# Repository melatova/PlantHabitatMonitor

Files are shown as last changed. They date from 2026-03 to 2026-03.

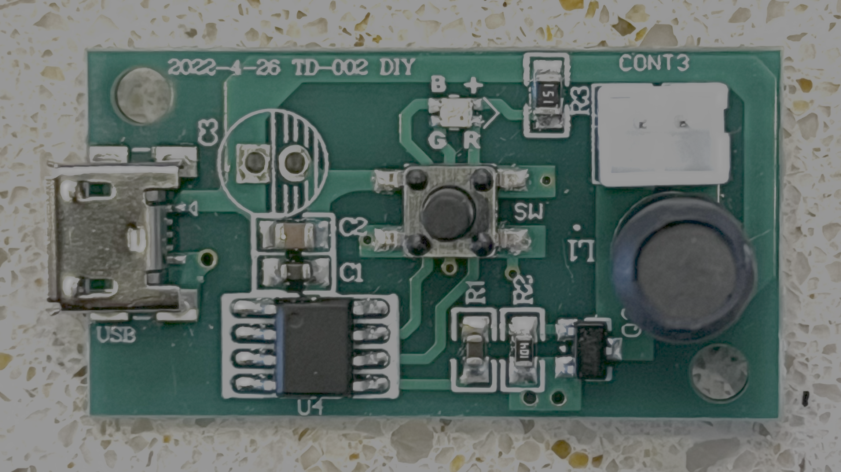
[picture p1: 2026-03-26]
images/Piezo_atomizer_board_TD-002-DIY-front.png

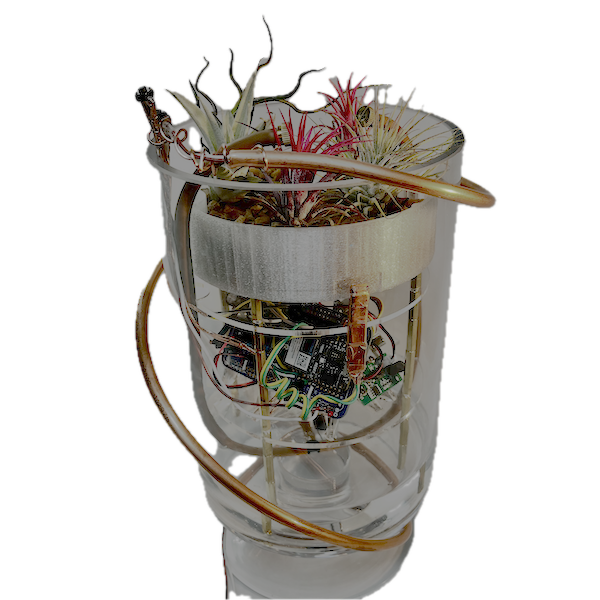
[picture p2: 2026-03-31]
images/Air_plant_sanctuary_2.png

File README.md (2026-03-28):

# 🌿 PlantHabitatMonitor
> **The Electro-Natural Plant Tech Sensor Menagerie**



[]()


---

### 🍃 Smart Tillandsia Care 
**A Multi‑Tiered IoT Air Plant Habitat**

```text
       [  plant  ]
            │
            │
    [sensors + display]
            │
            │
    [ water reservoir ]
    └─────────────────┘

A compact, slightly over‑engineered IoT habitat designed top  
Tillandsia (air plants) alive — despite my historically poor track record.

Built in five and a half days as part of a CNM IoT assignment,  
this project combines environmental sensing, automatic misting,  
and cloud monitoring in a sculptural glass enclosure.

* * * * * * * * * * * * * * * *

Features

  * Environmental monitoring**
    * Temperature & humidity (BME280)
    * Air quality sensing (analog gas sensor)
    * Capacitive moisture detection
    * Water reservoir level sensing

  * Automated plant care**
    * Piezo atomizing mist system
    * Water pump with automatic and manual control

  * Visual feedback**
    * NeoPixel status lighting
    * OLED system display with multiple pages

  * Cloud integration**
    * Live data publishing
    * Remote manual control via Adafruit IO dashboard

  * Modular physical design**
    * Multi‑tier vertical architecture
    * Custom laser‑cut and 3D‑printed structural components
    * Designed to live inside a glass hurricane vase

······························

System Architecture

Main loop structure:

loop()
├── readSensors()
├── updateButtons()
├── evaluateTriggers()
├── controlPumpAndMister()
├── updateNeoPixels()
├── updateOLED()
└── publishCloudData()

The system supports both automatic and manual operation modes,  
with local controls mirrored in the cloud dashboard.

······························

Hardware

  * Particle Photon 2**
  * BME280 temperature / humidity sensor**
  * Analog air quality sensor**
  * Capacitive moisture sensor**
  * DIY silver‑wire water level probes**
  * Piezo atomizer (TD‑002) + disc**
  * Water pump**
  * NeoPixel LED rings**
  * SSD1306 OLED display (I²C)**
  * MOSFET‑based power switching (post‑redesign)**

······························

Pinout (Core Signals)

| Component                | Pin |
|--------------------------|-----|
| OLED SDA / I²C           | D0  |
| OLED SCL / I²C           | D1  |
| NeoPixel Data            | D2  |
| Pump MOSFET Gate         | D4  |
| Mist MOSFET Gate         | D5  |
| Mist Button              | D7  |
| Mode Button              | D9  |
| Soil / Moisture Sensor   | A0  |
| Air Quality Sensor       | A1  |
| Reservoir Probe (ADC)    | A2  |

······························

Design Challenges & Lessons

  * Hardware that works on a home desk doesn’t always work at your away desk
  * Current draw issues revealed limitations of relay‑based switching
  * Redesigning the power stage with MOSFETs improved reliability
  * Wire routing and noise isolation matter in mixed‑signal systems
  * Iteration is unavoidable — and educational

······························

Piezo Atomizer Notes

The misting system uses a TD‑002 piezo atomizer module  
driven via a MOSFET rather than a relay due to current draw spikes.

Key considerations:
  * High‑frequency operation (~110 kHz)
  * 5V supply with adequate current headroom
  * Physical isolation from I²C wiring to reduce interference

Close‑up imagery and test videos are included in the project gallery.

······························

Gallery

https://youtu.be/lMnhnqs0L-Q

System Planning  
(images/planning_circuit_layer_arrangment.png)

Breadboard Prototyping  
(images/breadboard_testing.png)

MOSFET Redesign  
(images/changing_from_relays_to_MOSFETS.png)

Piezo Atomizer Detail  
(images/piezo_atomizer_plate.png)

Cloud Dashboard  
(images/adafruit_Dashboard.png)

Final Habitat  (updated as project progresses)
(images/PlantHabitatMonitor03.png)

······························

Files

/src        — firmware  
/images     — photos + macros  
/docs       — diagrams + notes  
/mechanical — laser‑cut + printed parts  

······························

Why This Exists

This project exists because air plants are beautiful, fragile,  
and completely unwilling to tolerate guesswork.

Rather than give up, I decided to give them sensors, firmware,  
and a cloud dashboard — and see what happened.

So far: the plants are alive.

······························

License

MIT License — enjoy, remix, and keep plants alive thoughtfully 🌿

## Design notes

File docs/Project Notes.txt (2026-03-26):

Plant Habitat Monitor Project 

---------------------------------------------------------

Take care of a plant and see how it's doing!

 ─────────────────────────────────────────────
   Hardware:
 ─────────────────────────────────────────────

     Device OS  : 5.8.0  (best for NeoPixels on Photon 2)
     NeoPixel   : D2, WS2812B, 24 LEDs (2x12 rings)
     BME280     : I2C 0x76
     OLED       : SSD1306 128x64, I2C 0x3C
     Soil sensor: A0 (capacitive)
     Air quality: A1 (Grove MP-503)
     Pump relay : D4
     Mist relay : D5
     Mode button: D9  (long=AUTO/MANUAL, short=advance OLED page)
     Mist button: D7  (dedicated tap for manual mist burst)
 ─────────────────────────────────────────────
   See plant data and control mister and pump

	Adafruit Dashboard Feeds
 ─────────────────────────────────────────────

     PUBLISH  -> temperature, humidity, plant-status,
                airreading, mode
     SUBSCRIBE<- pumponoff, misteronoff, pumpslider,
                modetoggle

 ─────────────────────────────────────────────
   Determine when habitat needs water

		THRESHOLDS
 ─────────────────────────────────────────────

  Calibration notes: air=3392, wet soil=3335, dry soil=3360, water=1460
  Air plants in gravel will sit closer to the dry end

SOIL_DRY_VALUE    = 3200;
SOIL_WET_VALUE    = 1500;
SOIL_WATER_THRESH = 30% below -> auto-water

MIST_TEMP_THRESH  = 30.0;    deg C above -> consider misting
MIST_HUM_THRESH   = 25.0;    %RH below  -> auto-mist fires

─────────────────────────────────────────────
   Display with environmental information

		OLED PAGES
─────────────────────────────────────────────
	
	PAGE_PLANT
	PAGE_CLIMATE
	PAGE_DEVICES
	PAGE_MODE
	"WATERING!" screen if pump is running
	"MISTING!"  screen while misting

starts with PAGE_PLANT

 ─────────────────────────────────────────────
   Continuously check plant environment

		LOOP
 ─────────────────────────────────────────────

	Sensor read every 10 s

	If in Auto Mode, waters plant if dry

	Keeps MQTT connection alive
   
	Publishes every 30 min

	Scrolls through OLED pages via 

	Shows Watering and Misting pages when activated
 
	Lights up neoPixels

  ─────────────────────────────────────────────
   Get readings from various sensors

		SENSOR READS
  ─────────────────────────────────────────────
	Converts soil moisture to percent
	Converts temperature to Farenheit
	Determines air quality from the readings

    tempC     = bme.readTemperature();
    humidRH   = bme.readHumidity();
    tempF     = tempC * 1.8 + 32;
    pressPA   = bme.readPressure();
    pressInHg = 0.0002953 * pressPA;
    soilRaw   = analogRead(SOIL_MOISTURE_PIN);
    soilPct   = mapSoilToPercent(soilRaw);
    airReading = airSensor.getValue();
    airQuality = airSensor.slope();

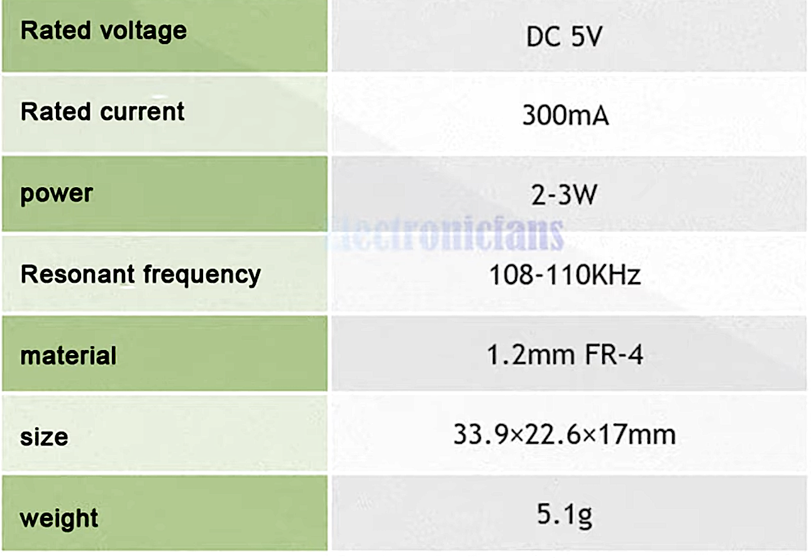
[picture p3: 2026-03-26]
docs/TD-002_specs.png

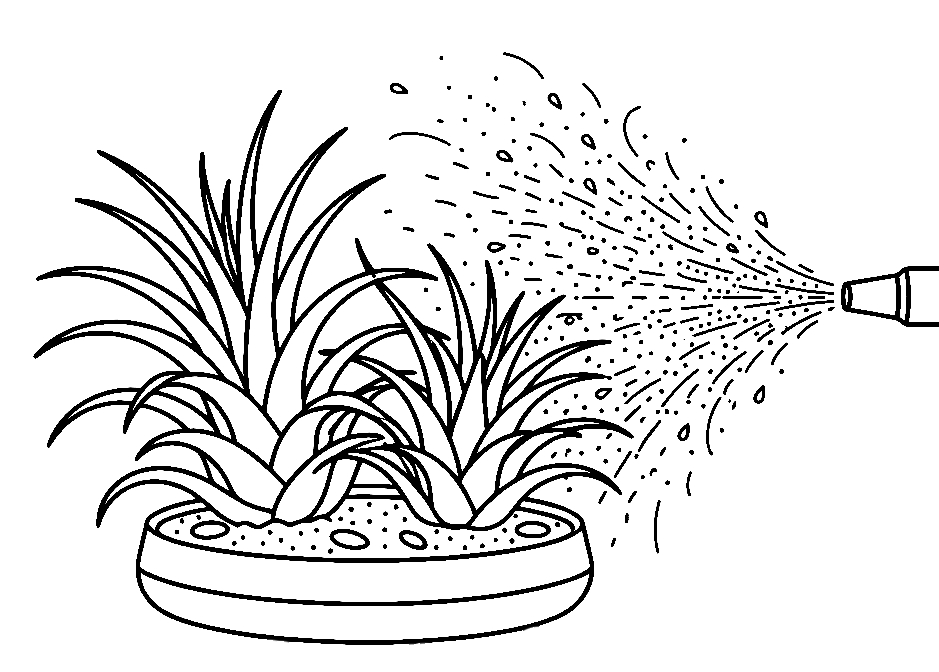
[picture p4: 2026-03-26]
images/Concept_Airplants_in_Gravel_auto_watering.png

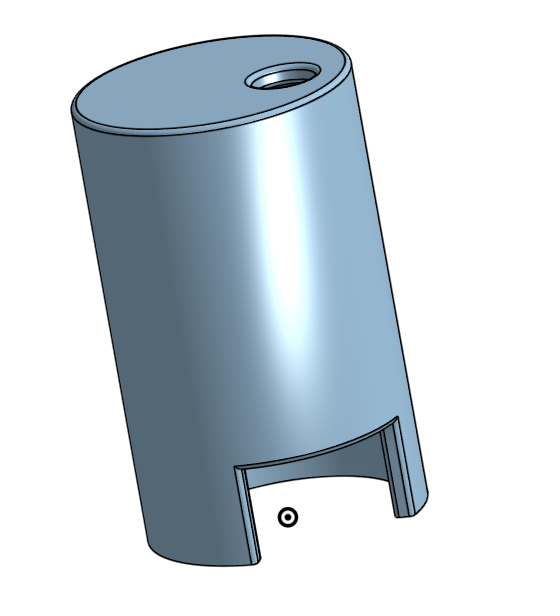
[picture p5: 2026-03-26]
mechanical/pump_cover.png

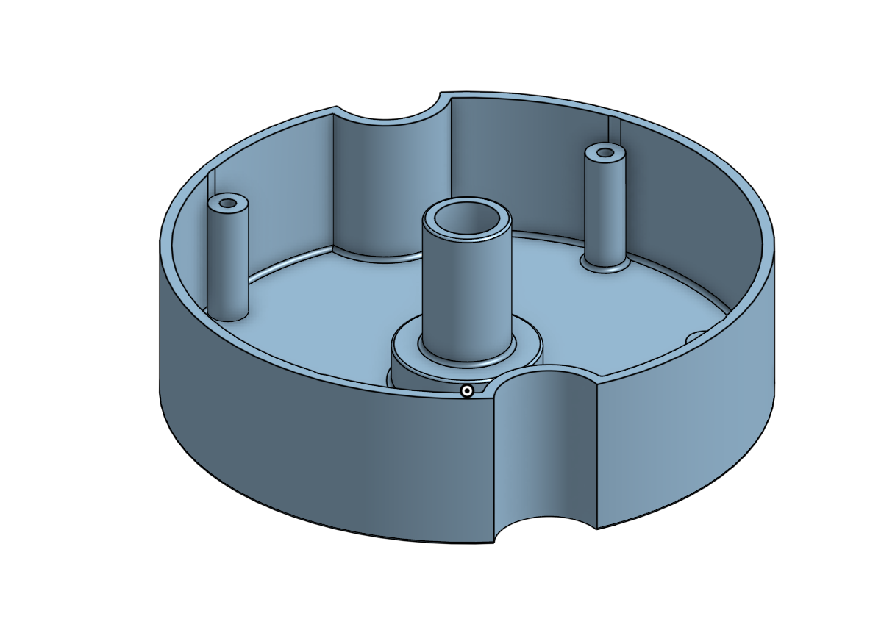
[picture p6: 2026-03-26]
mechanical/Gravel_dish_for_air_plants.png

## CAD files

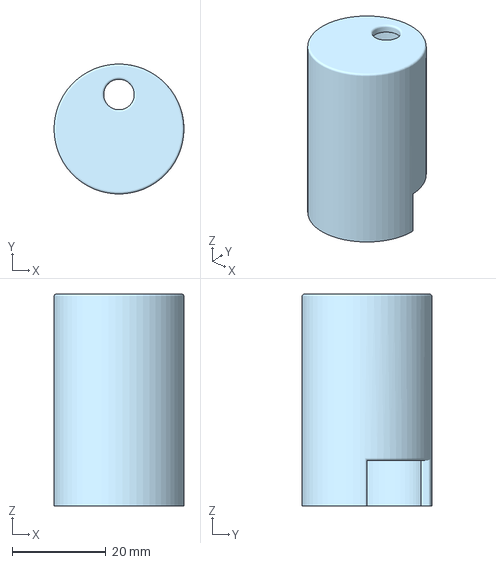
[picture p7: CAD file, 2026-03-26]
mechanical/5V_motorCover_sanderLegsFirst_printSmallHoleDown.3mf
27.7 x 27.7 x 45.2 mm

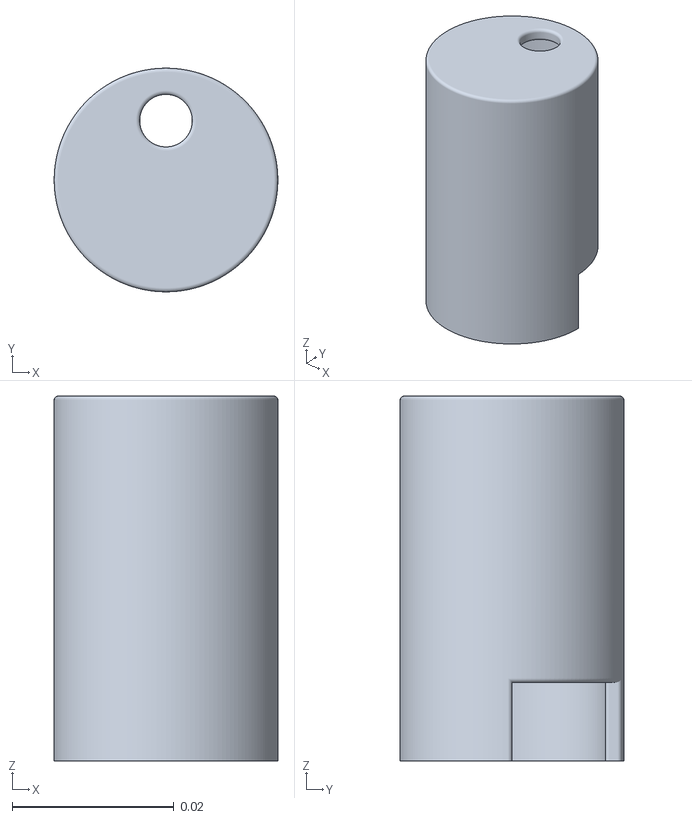
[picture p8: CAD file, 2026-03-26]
mechanical/5VMotorCover.stl
0.0277 x 0.0277 x 0.0452

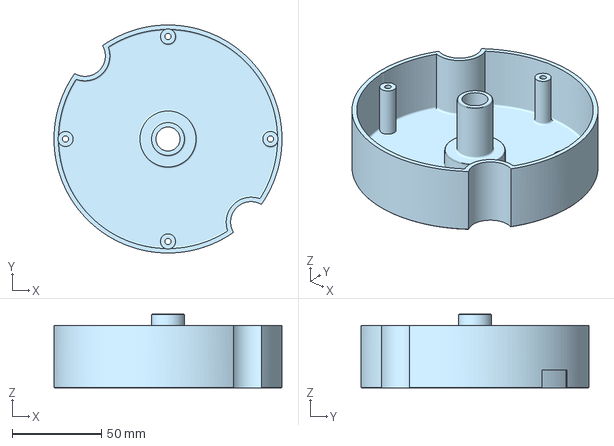
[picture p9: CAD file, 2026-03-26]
mechanical/Plant_habitat_gravel_dish.3mf
128.0 x 128.0 x 41.5 mm

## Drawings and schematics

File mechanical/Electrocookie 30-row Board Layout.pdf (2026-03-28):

# Electrocookie 30-row Board Layout — Plant Habitat Monitor

Photon 2 | 5V power rail | GND rail (16AWG copper loop) | MOSFET circuit | Sensors

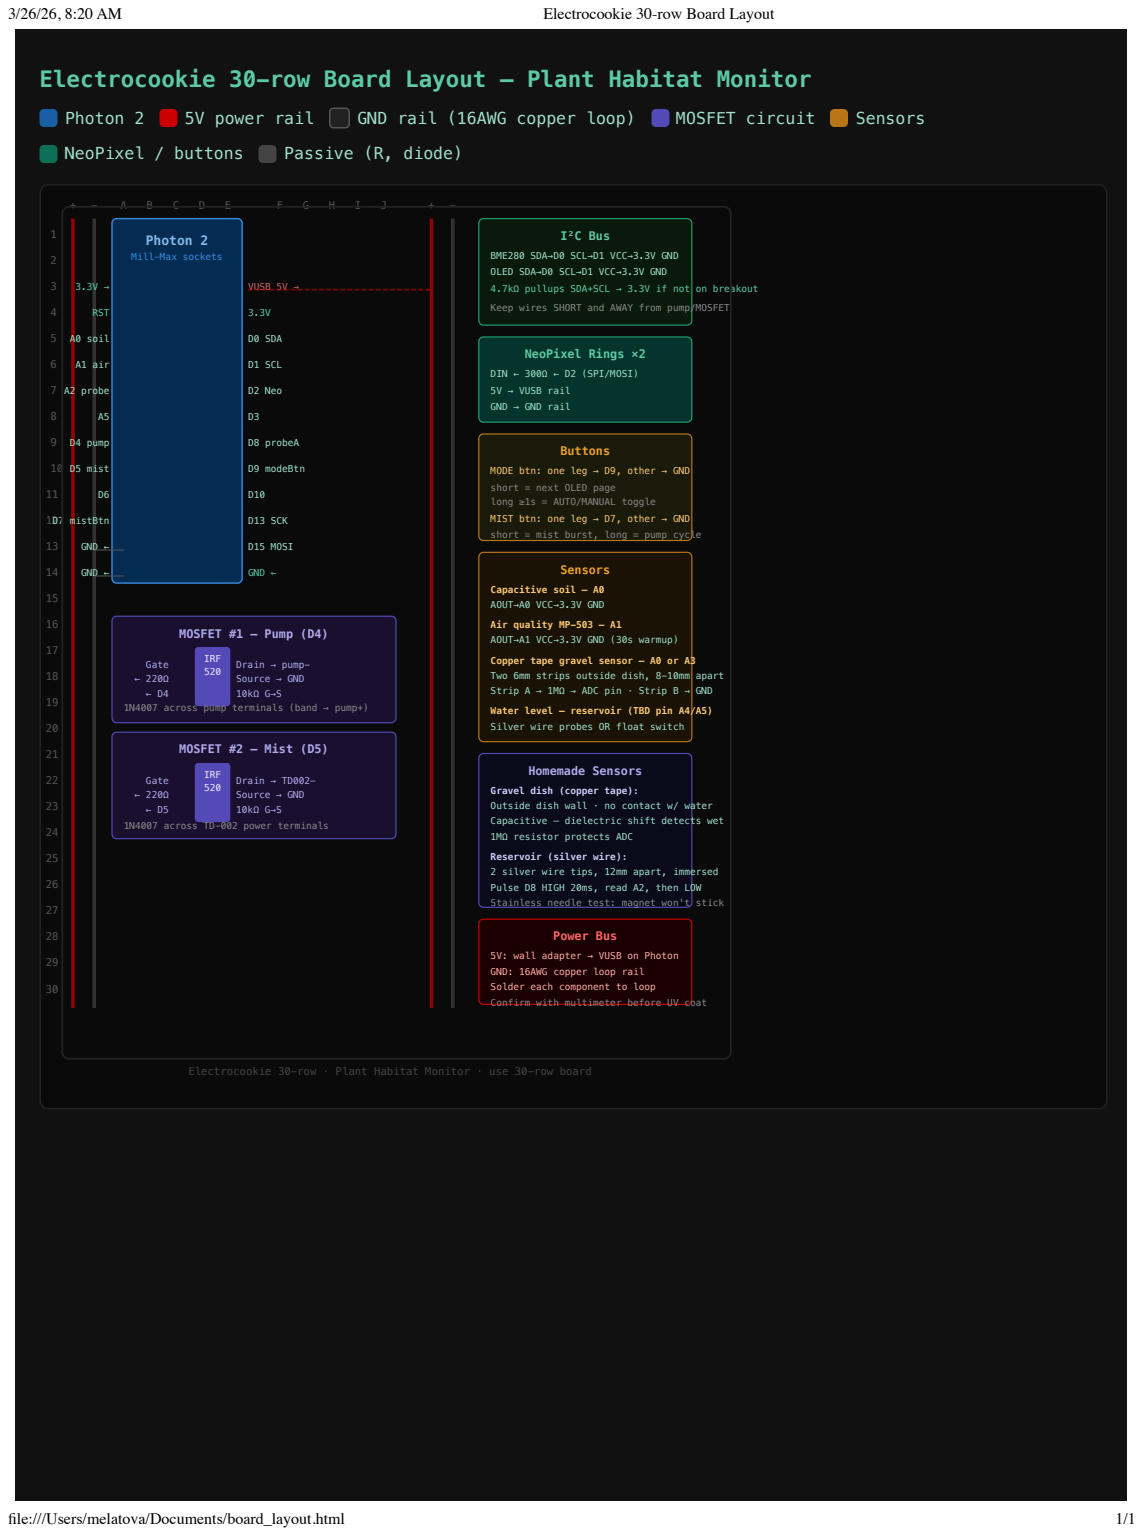
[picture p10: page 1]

BME280 SDA→D0 SCL→D1 VCC→3.3V GND
OLED SDA→D0 SCL→D1 VCC→3.3V GND
4.7kΩ pullups SDA+SCL → 3.3V if not on breakout
Keep wires SHORT and AWAY from pump/MOSFET

MODE btn: one leg → D9, other → GND
short = next OLED page
long ≥1s = AUTO/MANUAL toggle
MIST btn: one leg → D7, other → GND
short = mist burst, long = pump cycle

Capacitive soil — A0
AOUT→A0 VCC→3.3V GND
Air quality MP-503 — A1
AOUT→A1 VCC→3.3V GND (30s warmup)
Copper tape gravel sensor — A0 or A3
Two 6mm strips outside dish, 8-10mm apart
Strip A → 1MΩ → ADC pin · Strip B → GND
Water level — reservoir (TBD pin A4/A5)
Silver wire probes OR float switch

Gravel dish (copper tape):
Outside dish wall · no contact w/ water
Capacitive — dielectric shift detects wet
1MΩ resistor protects ADC
Reservoir (silver wire):
2 silver wire tips, 12mm apart, immersed
Pulse D8 HIGH 20ms, read A2, then LOW
Stainless needle test: magnet won't stick

5V: wall adapter → VUSB on Photon
GND: 16AWG copper loop rail
Solder each component to loop
Confirm with multimeter before UV coat

Electrocookie 30-row · Plant Habitat Monitor · use 30-row board

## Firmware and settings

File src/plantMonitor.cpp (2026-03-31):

// ============================================================
//  Project     :  Plant Habitat Monitor
//  Author      :  Nicole
//  Date        :  2/20/26  (updated 3/30)
//  Description :  Smart plant monitor — auto watering + misting,
//                 two DIY resistive moisture sensors, manual buttons,
//                 Adafruit IO dashboard, OLED display, NeoPixel ring.
//
//  Hardware confirmed working:
//    Device OS  : 5.8.0  (best for NeoPixels on Photon 2)
//    NeoPixel   : SPI1,  WS2812B, 12 LEDs (1 × 12-LED ring)
//    BME280     : I2C 0x76
//    OLED       : SSD1306 128×64, I2C 0x3C
//    Gravel sensor  : A5 (power pulse), A0 (analog read)  threshold 500–1500
//    Reservoir sensor: D8 (power pulse), A2 (analog read)  threshold 500
//    Air quality: A1 (Grove MP-503)
//    Pump MOSFET: D4
//    Mist MOSFET: D5
//    Mode button: D9  (short = next OLED page, long = AUTO/MANUAL toggle)
//    Mist button: D7  (short = mist burst,     long = pump cycle)
//
//  Adafruit IO feeds:
//    PUBLISH  -> temperature, humidity, plant-status, airreading, mode
//    SUBSCRIBE<- pumponoff, misteronoff, modetoggle

//   Zapier       (email/SMS webhooks via Particle.publish)
//
//  Future: reservoir level feed, SMS alert, OLED bitmap graphics
// ============================================================

#include "Particle.h"
#include "credentials.h"
#include "IoTClassroom_CNM.h"
#include "Adafruit_GFX.h"
#include "Adafruit_SSD1306.h"
#include "gfxDisplay.h"
#include "Adafruit_BME280.h"
#include "Adafruit_MQTT/Adafruit_MQTT_SPARK.h"
#include "Adafruit_MQTT/Adafruit_MQTT.h"
#include "neopixel.h"
#include "Colors.h"
#include "Air_Quality_Sensor.h"

// SYSTEM_THREAD(ENABLED) moves WiFi/cloud to a background thread
// so loop() never freezes waiting for network events.
SYSTEM_MODE(SEMI_AUTOMATIC);
SYSTEM_THREAD(ENABLED);

// ─────────────────────────────────────────────
//  PIN ASSIGNMENTS
// ─────────────────────────────────────────────
// Gravel dish sensor (air plants) — resistive, pulsed to prevent electrolysis
const int GRAVEL_POWER_PIN    = A5;  // OUTPUT — pulse HIGH to read
const int GRAVEL_ANALOG_PIN   = A0;  // INPUT  — analog read

// Water reservoir sensor — same resistive pulsed technique
const int RESERVOIR_POWER_PIN = D8;  // OUTPUT — pulse HIGH to read
const int RESERVOIR_ANALOG_PIN = A2; // INPUT  — analog read

const int AIR_QUALITY_PIN     = A1;  // Grove MP-503 analog out
const int PUMP_PIN            = D4;  // MOSFET gate — pump
const int MIST_PIN            = D5;  // MOSFET gate — TD-002 mister
const int MODE_BUTTON_PIN     = D9;  // INPUT_PULLUP — short/long press
const int MIST_BUTTON_PIN     = D7;  // INPUT_PULLUP — short/long press
// NeoPixel data -> SPI1 (confirmed working, Device OS 5.8.0)

// ─────────────────────────────────────────────
//  THRESHOLDS  (calibrated to sensors)
// ─────────────────────────────────────────────

// Gravel dish (air plants):
//   Calibration: dry gravel ~100-300, wet gravel ~1000+
//   Hysteresis: turn pump ON below 500, OFF above 1500
const int GRAVEL_ON_THRESH    = 500;   // below this -> auto-water
const int GRAVEL_OFF_THRESH   = 1500;  // above this -> stop pump
                                        // (wide hysteresis avoids chatter)

// Reservoir:
//   Probes immersed: reading > 500 = water present
//   Probes in air:   reading < 500 = reservoir low
const int RESERVOIR_THRESH    = 500;   // below -> reservoir low alert

// Auto-misting (BME280 driven)
const float MIST_TEMP_THRESH  = 30.0;  // °C above -> consider misting
const float MIST_HUM_THRESH   = 25.0;  // %RH below -> auto-mist fires

// Actuator timings
const unsigned long PUMP_RUN_MS      = 5000;   // 5 s per water cycle
const unsigned long PUMP_COOLDOWN_MS = 60000;  // 60 s min between cycles
const unsigned long MIST_RUN_MS      = 3000;   // 3 s per mist burst
const unsigned long MODE_LOCK_MS     = 5000;   // dashboard can't override button for 5 s
const unsigned long MIN_PUMP_ON_MS   = 3000;   // minimum pump ON time

// Hysteresis thresholds (used in autoWateringLogic)
const int SOIL_ON_THRESH      = GRAVEL_ON_THRESH;
const int SOIL_OFF_THRESH     = GRAVEL_OFF_THRESH;

// ─────────────────────────────────────────────
//  TIMING  (millis-based)
// ─────────────────────────────────────────────
const unsigned long SENSOR_INTERVAL_MS = 10000;
const unsigned long MQTT_INTERVAL_MS   = 1800000; // 30 min 
const unsigned long NEO_INTERVAL_MS    = 100;
const unsigned long OLED_PAGE_MS       = 5000;

unsigned long lastSensorMs             = 0;
unsigned long lastMqttMs               = 0;
unsigned long lastNeoMs                = 0;
unsigned long lastOledMs               = 0;
unsigned long pumpStartMs              = 0;
unsigned long pumpStopMs               = 0;
unsigned long mistStartMs              = 0;
unsigned long lastPhysicalModeChangeMs = 0;

// ─────────────────────────────────────────────
//  NEOPIXEL  (single 12-LED ring via SPI1)
// ─────────────────────────────────────────────
const int PIXEL_COUNT = 12;
Adafruit_NeoPixel pixel(PIXEL_COUNT, SPI1, WS2812B);
int sizeArray = sizeof(rainbow) / sizeof(rainbow[0]);

// ─────────────────────────────────────────────
//  HARDWARE OBJECTS
// ─────────────────────────────────────────────
const int OLED_RESET = -1;
Adafruit_SSD1306  display(OLED_RESET);
Adafruit_BME280   bme;
AirQualitySensor  airSensor(AIR_QUALITY_PIN);

// ─────────────────────────────────────────────
//  MQTT
// ─────────────────────────────────────────────
TCPClient           TheClient;
Adafruit_MQTT_SPARK mqtt(&TheClient, AIO_SERVER, AIO_SERVERPORT,
                          AIO_USERNAME, AIO_KEY);

Adafruit_MQTT_Publish feedTemperature (&mqtt, AIO_USERNAME "/feeds/temperature");
Adafruit_MQTT_Publish feedHumidity    (&mqtt, AIO_USERNAME "/feeds/humidity");
Adafruit_MQTT_Publish feedPlantStatus (&mqtt, AIO_USERNAME "/feeds/plant-status");
Adafruit_MQTT_Publish feedAirReading  (&mqtt, AIO_USERNAME "/feeds/airreading");
Adafruit_MQTT_Publish feedMode        (&mqtt, AIO_USERNAME "/feeds/mode");

Adafruit_MQTT_Subscribe subPumpButton (&mqtt, AIO_USERNAME "/feeds/pumponoff");
Adafruit_MQTT_Subscribe subMistButton (&mqtt, AIO_USERNAME "/feeds/misteronoff");
Adafruit_MQTT_Subscribe subModeToggle (&mqtt, AIO_USERNAME "/feeds/modetoggle");

// ─────────────────────────────────────────────
//  SENSOR DATA
// ─────────────────────────────────────────────
float tempC = 0, tempF = 0, pressPA = 0, pressInHg = 0, humidRH = 0;
int   gravelRaw = 0;        // raw ADC from gravel dish sensor
int   reservoirRaw = 0;     // raw ADC from reservoir sensor
bool  reservoirLow = false; // true when reservoir needs refill
float airReading = 0;
int   airQuality = 0;

// ─────────────────────────────────────────────
//  STATE
// ─────────────────────────────────────────────
bool modeAuto           = true;
bool pumpRunning        = false;
bool misterRunning      = false;
bool alertSentThisCycle = false;

// ─────────────────────────────────────────────
//  OLED PAGE STATE MACHINE
//
//  Normal cycle (auto-advances every 5 s, or short-press D9):
//    PAGE_BOOT    -- title + timestamp (shown once at startup)
//    PAGE_PLANT   -- gravel moisture + humidity
//    PAGE_CLIMATE -- temp F + air quality + pressure
//    PAGE_DEVICES -- mister + pump + reservoir status
//    PAGE_MODE    -- AUTO / MANUAL watering mode
//
//  Interrupt pages (override while active):
//    pumpRunning   -> "WATERING!" screen
//    misterRunning -> "MISTING!"  screen
//
//  GRAPHICS:
//  Next step, add in bitmaps.
//  Finished bitmaps in gfxDisplay.h:
//    BITMAP_TEMP_F, BITMAP_BAROMETER, BITMAP_RH_PERCENT
//  Still to create:
//    BITMAP_PLANT_HAPPY, BITMAP_PLANT_DRY
//    BITMAP_MIST, BITMAP_PUMP, BITMAP_AUTO, BITMAP_MANUAL
// ─────────────────────────────────────────────
enum OledPage {
    PAGE_BOOT    = 0,
    PAGE_PLANT   = 1,
    PAGE_CLIMATE = 2,
    PAGE_DEVICES = 3,
    PAGE_MODE    = 4,
    PAGE_COUNT   = 5
};
int currentPage = PAGE_BOOT;

// ─────────────────────────────────────────────
//  BUTTON DEBOUNCE STATE
// ─────────────────────────────────────────────
int           lastModeButtonState = HIGH;
unsigned long modeButtonPressMs   = 0;
int           lastMistButtonState = HIGH;
unsigned long mistButtonPressMs   = 0;
const int     DEBOUNCE_MS         = 50;

// ─────────────────────────────────────────────
//  FORWARD DECLARATIONS
// ─────────────────────────────────────────────
void  MQTT_connect();
bool  MQTT_ping();
void  readSensors();
int   readResistiveSensor(int powerPin, int analogPin);
void  drawOledPage();
void  advancePage();
void  handleModeButton();
void  handleMistButton();
void  handleSubscriptions();
void  publishToAdafruitIO();
void  autoWateringLogic();
void  autoMistingLogic();
void  startPump();
void  stopPump();
void  startMister();
void  stopMister();
void  updateNeoPixel();
String getAirQualityLabel(int val);
String getTimeStamp();

// ─────────────────────────────────────────────
//  SETUP
// ─────────────────────────────────────────────
void setup() {
    Serial.begin(9600);
    waitFor(Serial.isConnected, 10000);
    Serial.println("Plant Monitor booting...");

    // -- GPIO --------------------------------------
    pinMode(PUMP_PIN,             OUTPUT); digitalWrite(PUMP_PIN, LOW);
    pinMode(MIST_PIN,             OUTPUT); digitalWrite(MIST_PIN, LOW);
    pinMode(MODE_BUTTON_PIN,      INPUT_PULLUP);
    pinMode(MIST_BUTTON_PIN,      INPUT_PULLUP);
    pinMode(GRAVEL_POWER_PIN,     OUTPUT); digitalWrite(GRAVEL_POWER_PIN, LOW);
    pinMode(GRAVEL_ANALOG_PIN,    INPUT);
    pinMode(RESERVOIR_POWER_PIN,  OUTPUT); digitalWrite(RESERVOIR_POWER_PIN, LOW);
    pinMode(RESERVOIR_ANALOG_PIN, INPUT);

    // Suppress onboard RGB — prevents interference with NeoPixel SPI
    RGB.control(true);
    RGB.color(0, 0, 0);

    // -- NeoPixel ----------------------------------
    pixel.begin();
    pixel.setBrightness(50);
    pixel.setPixelColor(0, pixel.Color(0, 160, 140)); // single teal pixel on boot
    pixel.show();
    Serial.println("NeoPixel OK");

    // -- I2C — must come before BME280 and OLED ---
    Wire.begin();

    // -- BME280 ------------------------------------
    if (!bme.begin(0x76)) {
        Serial.println("BME280 not found at 0x76 -- check wiring");
    } else {
        Serial.println("BME280 OK");
    }

    // -- OLED --------------------------------------
    display.begin(SSD1306_SWITCHCAPVCC, 0x3C);
    display.setTextColor(WHITE);
    display.setTextSize(1);
    display.clearDisplay();
    display.display();
    Serial.println("OLED OK");

    // -- WiFi + Particle cloud ---------------------
    // waitFor() gives each step a time limit then continues regardless.
    WiFi.on();
    WiFi.connect();
    waitFor(WiFi.ready, 15000);
    if (WiFi.ready()) {
        Serial.println("WiFi connected");
        Particle.connect();
        waitFor(Particle.connected, 10000);
        if (Particle.connected()) {
            Particle.syncTime();
            Time.zone(-6); // Mountain Time — adjust +1 for MDT (summer)
            Serial.println("Particle cloud connected — time synced");
        }
    } else {
        Serial.println("WiFi timeout -- continuing offline");
    }

    // -- Air quality sensor ------------------------
    if (airSensor.init()) {
        Serial.println("Air sensor OK");
    } else {
        Serial.println("Air sensor init failed");
    }

    // -- MQTT subscriptions ------------------------
    mqtt.subscribe(&subPumpButton);
    mqtt.subscribe(&subMistButton);
    mqtt.subscribe(&subModeToggle);

    // -- Boot OLED page — show title + timestamp ---
    // Displayed once at startup before cycling begins
    display.clearDisplay();
    display.setTextSize(2);
    display.setCursor(4, 2);  display.print("Plant");
    display.setCursor(4, 22); display.print("Monitor");
    display.setTextSize(1);
    display.setCursor(4, 46); display.print("for happy plants");
    display.setCursor(4, 56); display.print(getTimeStamp());
    display.display();
    Serial.printf("Boot time: %s\n", getTimeStamp().c_str());

    // Seed timers
    lastSensorMs = millis() - SENSOR_INTERVAL_MS + 3000; // first read in 3 s
    lastMqttMs   = millis();
    lastNeoMs    = millis();
    lastOledMs   = millis();
    pumpStopMs   = millis() - PUMP_COOLDOWN_MS; // pump ready immediately

    Serial.println("Plant Monitor ready!");
}

// ─────────────────────────────────────────────
//  LOOP
//  Traffic controller — delegates, never blocks.
// ─────────────────────────────────────────────
void loop() {
    unsigned long now = millis();

    // Sensor read every 10 s — auto logic runs ONLY after fresh data.
    // Keeping auto logic here prevents it from re-evaluating stale
    // gravelRaw thousands of times per second, which caused the pump
    // to restart immediately after stopping before the next real read.
    if (now - lastSensorMs >= SENSOR_INTERVAL_MS) {
        lastSensorMs = now;
        readSensors();
        if (modeAuto) {
            autoWateringLogic();
            autoMistingLogic();
        }
    }

    // Auto-off: pump and mister — checked every loop for accurate timing.
    // These use millis() elapsed time, not sensor data, so they are safe
    // to check continuously without causing the re-trigger problem above.
    if (pumpRunning   && (now - pumpStartMs >= PUMP_RUN_MS)) stopPump();
    if (misterRunning && (now - mistStartMs >= MIST_RUN_MS)) stopMister();

    // Buttons
    handleModeButton();
    handleMistButton();

    // MQTT keep-alive + subscriptions
    MQTT_connect();
    MQTT_ping();
    mqtt.processPackets(10);
    handleSubscriptions();

    // Publish every 30 min
    if (now - lastMqttMs >= MQTT_INTERVAL_MS) {
        lastMqttMs = now;
        publishToAdafruitIO();
    }

    // OLED: auto-advance page every 5 s (skip boot page after first cycle)
    if (now - lastOledMs >= OLED_PAGE_MS) {
        lastOledMs = now;
        if (!pumpRunning && !misterRunning) {
            advancePage();
        }
    }
    drawOledPage();

    // NeoPixel animation tick
    if (now - lastNeoMs >= NEO_INTERVAL_MS) {
        lastNeoMs = now;
        updateNeoPixel();
    }
}

// ─────────────────────────────────────────────
//  RESISTIVE SENSOR READ  (shared helper btw both sensors)
//
//  Both DIY sensors use the same technique:
//    1. Pulse power pin HIGH for 20ms — enough to get a stable read
//    2. Read the analog voltage
//    3. Pull power LOW immediately — prevents electrolysis on the wires
//
//  Dry / no water : high resistance → little current → low ADC
//  Wet / has water : low resistance → more current → higher ADC
//  (opposite of capacitive sensor — no inversion needed)
// ─────────────────────────────────────────────
int readResistiveSensor(int powerPin, int analogPin) {
    digitalWrite(powerPin, HIGH);
    delay(20);                      // 20 ms stabilisation pulse
    int val = analogRead(analogPin);
    digitalWrite(powerPin, LOW);
    return val;
}

// ─────────────────────────────────────────────
//  SENSOR READS
// ─────────────────────────────────────────────
void readSensors() {
    // BME280
    tempC     = bme.readTemperature();
    humidRH   = bme.readHumidity();
    tempF     = tempC * 1.8 + 32.0;
    pressPA   = bme.readPressure();
    pressInHg = 0.0002953 * pressPA;

    // Gravel dish sensor (air plants)
    gravelRaw = readResistiveSensor(GRAVEL_POWER_PIN, GRAVEL_ANALOG_PIN);

    // Reservoir water level sensor
    reservoirRaw = readResistiveSensor(RESERVOIR_POWER_PIN, RESERVOIR_ANALOG_PIN);
    reservoirLow = (reservoirRaw < RESERVOIR_THRESH);

    // Air quality
    airReading = airSensor.getValue();
    airQuality = airSensor.slope();

    Serial.printf("[BME]   %.1fF  %.1f%%RH  %.2f inHg\n", tempF, humidRH, pressInHg);
    Serial.printf("[GRVL]  raw=%d  %s\n", gravelRaw,
                  gravelRaw >= GRAVEL_ON_THRESH ? "moist" : "dry");
    Serial.printf("[RESV]  raw=%d  %s\n", reservoirRaw,
                  reservoirLow ? "LOW" : "OK");
    Serial.printf("[AIR]   %.1f  %s\n", airReading,
                  getAirQualityLabel(airQuality).c_str());
}

String getAirQualityLabel(int val) {
    if (val == AirQualitySensor::FRESH_AIR)     return "Good";
    if (val == AirQualitySensor::LOW_POLLUTION)  return "Fair";
    if (val == AirQualitySensor::HIGH_POLLUTION) return "Poor";
    if (val == AirQualitySensor::FORCE_SIGNAL)   return "Alert";
    return "---";
}

// ─────────────────────────────────────────────
//  TIMESTAMP
//
//  Returns current time as "HH:MM:SS" string.
//  Uses Particle.syncTime() called in setup()
//  Daylight savings for Time.zone():
//  Time.zone(-6) = MST.  Use -7 for MDT (summer).
// ─────────────────────────────────────────────
String getTimeStamp() {
    String dateTime = Time.timeStr();
    return dateTime.substring(11, 19); // extract HH:MM:SS
}

// ─────────────────────────────────────────────
//  OLED STATE MACHINE
// ─────────────────────────────────────────────
void advancePage() {
    // Boot page shows once, then skips into normal cycle
    if (currentPage == PAGE_BOOT) {
        currentPage = PAGE_PLANT;
    } else {
        // Cycle PAGE_PLANT -> PAGE_CLIMATE -> PAGE_DEVICES -> PAGE_MODE -> back
        currentPage = PAGE_PLANT + (currentPage - PAGE_PLANT + 1) % (PAGE_COUNT - 1);
    }
}
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

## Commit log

2026-03-26 Clean commit without large video files
    [5VMotorCover.stl, 5V_motorCover_sanderLegsFirst_printSmallHoleDown.3mf, Plant_habitat_gravel_dish.3mf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]
2026-03-30 added new sensors
2026-03-31 forgot to mention Zapier alert in description
    [plantMonitorFritz_recovered.fzz]
